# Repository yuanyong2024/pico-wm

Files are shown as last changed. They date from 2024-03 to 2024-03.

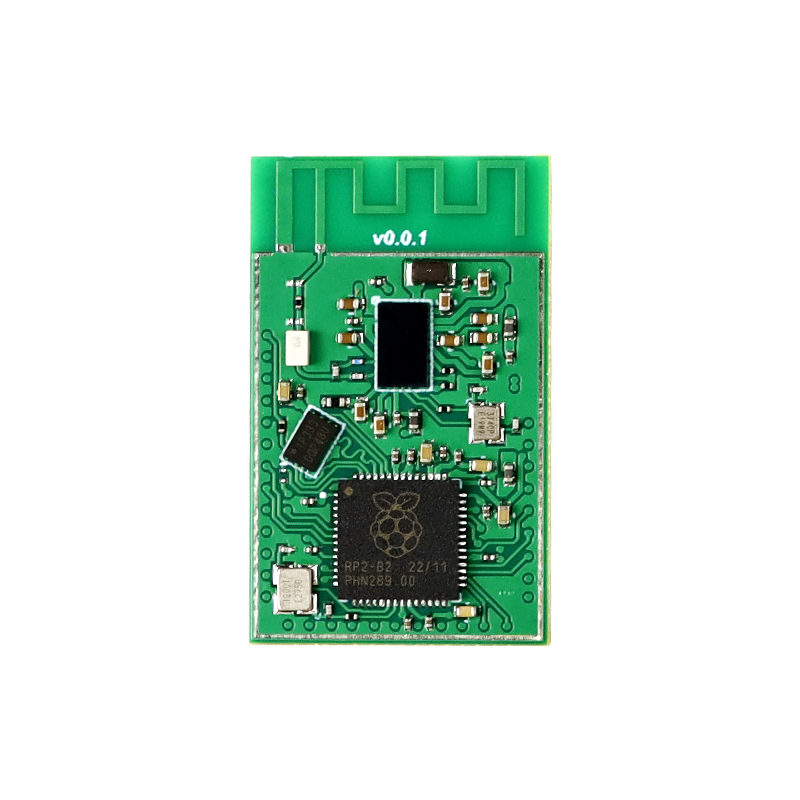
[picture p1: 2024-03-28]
pictures/2.jpg

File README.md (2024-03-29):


# Introduction
As a hardware engineer, it's always have difficulties to coding in python than C.Plus,I'm a fan of Raspberry Pi's hardware. So when they release the pico w and when i saw the schematic for it. 
I was thinking well I should build one module based on that architecture with below several reasons
1. Keep motivated on learn circuitpython.
2. Learn how to design a compact module.
3. improve the skill of tuning the antenna.
4. gain more on how to design a product.
5. I name it pico wm (pico w means its a variant of official Raspberry Pi pico w and m means it's a module)
So there is. I made it work even at the first verison. And optimized a little bit on v0.0.2. Probably there is a v0.0.3 if I find out something that need to get improved.

# Features:
1. use the same wifi chip(infineon CY43439) and circuitry like pico w. So wirelss function api is exactly the same(not like most of the rp2040+esp solution on market)
2. Flash size is the same like pico w (16Mb)
3. 6 layer board design with a complete ground on bottom layer. Improved the signal integraty. But also increased the costs -:(
4. compact size(28.5x17.5mm), so that it can be suitable for most of the situation.
5. All the GPIO had been exposed at the bottom side in a LGA footprint.
6. 50ohm impedance achieved for the RF trace.
7. onboard WiFi/BLE antenna.But obviously not as good as official pico w for now -:(
8. Reserved for a top shield cover feature.
9. all  the vias on the pcb is filled plating.
10. optimize the power topology, make it easier to design the carrier board based on this module.
11. Ofcourse totally open-sourced.

# Limitations:
1. The only limitation for this module would be the RF performance, Still need more time to tuning it.
2. And because I need to make sure the module is functioning well after SMT, so I didnot populate the shield cover yet.

# considering support me?
Building the module definitley take time and energy.
And also it's cost a lot. As the module itself is a six layer board and I'm using the expensive Infineon chip. So I would appreciate anyone who can support me by purchase it from [this link](https://www.elecrow.com/pico-wm.html)

# Attentions:
1. This is just a module. So need customer build a carrier board for it.
2. Those who interested in this module can use the picoduino as a start point and use the pico w m schematic and pcb lib from that picoduino open source file.
3. I will also build a feather compatible one later.

# useful links:
[pico w datasheet](https://datasheets.raspberrypi.com/picow/pico-w-datasheet.pdf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..)

[raspberry pi pico documentation](https://www.raspberrypi.com/documentation/microcontrollers/raspberry-pi-pico.html#raspberry-pi-pico-w)

[picoduino design file](https://github.com/yuanyong2024/picoduino)

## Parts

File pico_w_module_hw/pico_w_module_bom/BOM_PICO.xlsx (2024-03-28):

Designator | Quantity | Footprint | MFG | PN | Value
U4 | 1 | USON8_3X2MM | WINBOND | W25Q16JVUXIQ | N/A
U3 | 1 |  | Raspberrypi | RP2040 | N/A
U2 | 1 | LFB212G45CG7D227 | muRata | LFB212G45CG7D227 | N/A
U1 | 1 | CY43439 | Infineon | CYW43439KUBG | N/A
R8, R9 | 2 | R0201 | YAGEO | RC0201FR-071KL | 1K
R5 | 1 | R0201 | YAGEO | AF0201JR-07220RL | 220R
R4 | 1 | R0201 | YAGEO | RC0201FR-070RL | 0R
R3 | 1 | R0402 | YAGEO | RC0402FR-0722RL | 22R
R2 | 1 | R0201 | YAGEO | RC0201JR-0710KL | 10K
R1 | 1 | R0201 | YAGEO | RC0201DR-07470RL | 470R
Q2 | 1 | 2520 | EPSON | Q24FA20H00687 | 12MHz
Q1 | 1 | Q22FA12800078 | EPSON | Q22FA12800078 | 37.4MHz
L2 | 1 | l0201 | muRata | LQP03PN4N7J02D | 4.7nH
L1 | 1 | L0805 | TAIYO YUDEN | BRC2012T2R2MD | 2.2uH
FB1, FB2, FB3 | 3 | L0402 | muRata | BLM15AG601SN1D | 600R@100MHz
C23, C25, C26, C30, C40 | 5 | C0402 | muRata | GRM155R61A106ME44D | 10uF
C18, C19 | 2 | C0201 | muRata | GRM0335C1H150FA01D | 15pF
C16, C17 | 2 | C0201 | muRata | GRM0335C1H180JA01D | 18pF
C12, C15 | 2 | C0201 | muRata | GRM0335C1H100JA01D | 10pF
C8, C10, C20, C21, C24, C27, C28, C29, C31, C32, C33, C34, C35, C36, C37, C38, C39 | 17 | C0201 | muRata | GRM033Z71A104KE14D | 0.1uF
C1, C2, C3, C4, C5, C6, C7, C9, C11, C22 | 10 | C0402 | muRata | GRM155R61A475KEAAD | 4.7uF

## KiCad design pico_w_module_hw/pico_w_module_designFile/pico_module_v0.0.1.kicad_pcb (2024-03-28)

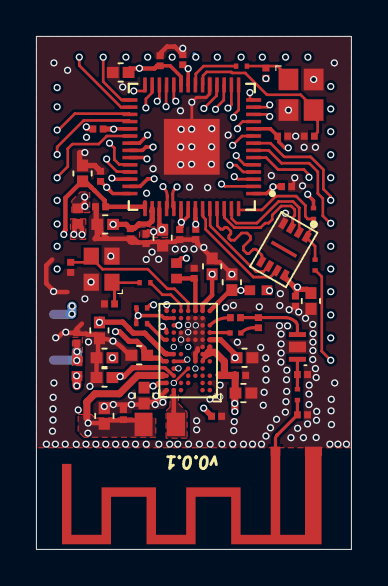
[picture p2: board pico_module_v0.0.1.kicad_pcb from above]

Board: 6 copper layers, 17.5 x 28.5 mm, 61 parts (0 on the bottom side), 70 nets.

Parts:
ANT1: U.FL-R-SMT-1(10); AN043_2.4GHZ
C1, C2, C3, C4, C5, C6, C7, C9, C11, C22, C23, C25, C26, C30, C40: C0402 12pF 50V; C0402
C8, C10, C20, C21, C31: C0402 12pF 50V; C0201
C12, C13, C14, C15, C16, C17, C18, C19, C24, C27, C28, C29, C32, C33, C34, C35, C36, C37, C38, C39: C0201 DNP; C0201
FB1, FB2, FB3: Ferrite 33Ohm 6A; L0402
L1: Inductor 6.8uH 30%; L0805
L2: L0603 470nH 1.4A; l0201
Q1: 37.4MHz; Q22FA12800078
Q2: 12MHz; 2520
R1, R2, R4, R5, R8, R9, R10: R0402 DO NOT PLACE; R0201
R3: R0402 1K 5% 1/16W; R0402
U1: CYW43439KUBG; CY43439
U2: LFB212G45CG7D227
U3: RP2040
U4: W25Q16JVUXIQ; USON8_3X2MM
U5: PICO_W_MODULE; PICO_M_SMT

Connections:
1.1V: C25.2, C26.2, C27.2, C28.2, C29.2, U3.23, U3.45, U3.50
ADC_REF: C23.2, C24.2, U3.43, U5.36
BOOTSEL: R9.2, U5.2
GND: ANT1.2, ANT1.3, C1.1, C2.1, C3.1, C4.1, C5.1, C6.1, C7.1, C8.1, C9.1, C10.1, C11.1, C13.1, C14.1, C16.1, C17.1, C18.1, C19.1, C20.1, C21.1, C22.1, C23.1, C24.1, C25.1, C26.1, C27.1, C28.1, C29.1, C30.1, C31.1, C32.1, C33.1, C34.1, C35.1, C36.1, C37.1, C38.1, C39.1, C40.1, Q1.2, Q1.4, Q2.2, Q2.4, U1.A7, U1.B1, U1.B6, U1.D4, U1.E3, U1.G2, U1.H2, U1.H3, U1.H4, U1.J2, U1.J3, U1.J5, U1.K2, U1.L2, U1.L3, U1.L4, U2.G, U3.19, U3.57, U4.4, U5.1, U5.15, U5.27, U5.37, U5.39, U5.41
GPIO0: U3.2, U5.3
GPIO1: U3.3, U5.4
GPIO2: U3.4, U5.5
GPIO3: U3.5, U5.6
GPIO4: U3.6, U5.7
GPIO5: U3.7, U5.8
GPIO6: U3.8, U5.9
GPIO7: U3.9, U5.10
GPIO8: U3.11, U5.11
GPIO9: U3.12, U5.12
GPIO10: U3.13, U5.13
GPIO11: U3.14, U5.14
GPIO12: U3.15, U5.16
GPIO13: U3.16, U5.17
GPIO14: U3.17, U5.18
GPIO15: U3.18, U5.19
GPIO16: U3.27, U5.23
GPIO17: U3.28, U5.24
GPIO18: U3.29, U5.25
GPIO19: U3.30, U5.26
GPIO20: U3.31, U5.30
GPIO21: U3.32, U5.31
GPIO22: U3.34, U5.32
GPIO26: U3.38, U5.33
GPIO27: U3.39, U5.34
GPIO28: U3.40, U5.35
MCU_VDD: FB3.1, U5.38
M_USB_N: U3.46, U5.29
M_USB_P: U3.47, U5.28
M_VCC: C30.2, C32.2, C33.2, C34.2, C35.2, C36.2, C37.2, C38.2, C39.2, C40.2, FB3.2, R10.2, U3.1, U3.10, U3.22, U3.33, U3.42, U3.44, U3.48, U3.49, U4.8
NetANT1_1: ANT1.1, C13.2, R4.1
NetC7_2: C7.2, R3.2, U1.H1
NetC8_2: C8.2, FB2.2, U1.M3
NetC12_1: C12.1, C15.2, U2.O
NetC12_2: C12.2, U1.K1
NetC14_2: C14.2, R4.2, U2.I
NetC15_1: C15.1, L2.1
NetC16_2: C16.2, Q1.3, U1.M4
NetC17_2: C17.2, Q1.1, R5.1
NetC18_2: C18.2, Q2.3, U3.20
NetC19_2: C19.2, Q2.1, R8.1
NetL1_1: L1.1, U1.A6
NetL2_2: L2.2, U1.J1
NetR1_2: R1.2, U1.K6
NetR2_2: R2.2, U1.H7
NetR5_2: R5.2, U1.M5
NetR8_2: R8.2, U3.21
NetU1_E6: U1.E6, U1.G6, U3.35
QSPI_SCLK: U3.52, U4.6
QSPI_SD0: U3.53, U4.5
QSPI_SD1: U3.55, U4.2
QSPI_SD2: U3.54, U4.3
QSPI_SD3: U3.51, U4.7
RF_VDD: C31.2, FB1.1, U5.40
RUN: U3.26, U5.22
SDIO_CLK: U1.M7, U3.41
SDIO_CS: U1.J7, U3.37
SDIO_DIO: R1.1, R2.1, U1.L6, U1.L7, U3.36
SWCLK: U3.24, U5.20
SWDIO: U3.25, U5.21
VDD_BAT: C11.2, C22.2, FB1.2, U1.B7, U1.F6, U1.F7
VIN_LDO: C1.2, C2.2, C20.2, L1.2, U1.C7, U1.M2
VOUT_3P3: C5.2, C6.2, R3.1, U1.E7, U1.M1
VOUT_CORE: C3.2, C10.2, U1.C6, U1.D3, U1.G4
VOUT_LN: C4.2, C9.2, C21.2, FB2.1, U1.D6, U1.E2, U1.F1, U1.F2, U1.G1
~QSPI_SS: R9.1, R10.1, U3.56, U4.1

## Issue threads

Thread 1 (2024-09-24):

Questions about PICO-WM

metermult, 2024-09-24:
Hello,

I have several questions and want to pick your brain as to how the development of this product was completed and if v0.0.2 or v0.0.3 is on the horizon.
1) What simulation software did you use for the antenna? I believe that there was a few vias as well that may be just a little far apart but I was just visually looking.
2) Do you plan on supporting the [rp2350](https://www.raspberrypi.com/products/raspberry-pi-pico-2/) in the near future?

I will buy and will take a look at this. Maybe do some signal analysis on the device and let you know what.

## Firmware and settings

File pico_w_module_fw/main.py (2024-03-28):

from machine import UART,Pin,I2C
import network
import socket
import time

led = Pin(16,Pin.OUT)
led.value(1)

timeout_count = 2
while timeout_count:
    print(f"timeout count {timeout_count} before setting up the Wi-Fi config")
    timeout_count-=1
    time.sleep(1)
    
print("\r\nWelcome to the setup process for picoduino, Please follow below three steps to control the onboard led via browser\r\n")
print('Please input your Wi-Fi name:')
wifi_name = input()
print(f'your Wi-Fi name is "{wifi_name}",now please input your Wi-Fi password')
password = input()
print(f'your Wi-Fi password is "{password}"')
print("well done, your picoduino now is trying to connect to your Wi-Fi network")




#connect to wifi router and return the ip
def connect():
    #Connect to WLAN
    wlan = network.WLAN(network.STA_IF)
    wlan.active(True)
    wlan.connect(wifi_name, password)
    retry_count = 10
    while wlan.isconnected() == False:
        print('Waiting for connection...')
        #blink for 1s insted of delay 1s
        for i in range(5):
            led.value(0)
            time.sleep(0.1)
            led.value(1)
            time.sleep(0.1)
            
        retry_count-=1
        if retry_count==0:
            break
    
    if retry_count == 0:
        print("ooops, picoduino cannot connect to you Wi-Fi network, please check your Wi-Fi name and password and press reset button for a pretry.!!!!!!!!!!")
        while True:
            led.value(0)
            time.sleep(1)
            led.value(1)
            time.sleep(1)
        
    led.value(1)   
    ip = wlan.ifconfig()[0]
    print(f'Connected on {ip}')
    print("\r\nPlease copy the above ip address to browser and press enter(or return on MAC OS)")
    print("And have fun with thet LED on and off example -:)")
    return ip

  
def open_socket(ip):
    # Open a socket
    address = (ip, 80)
    connection = socket.socket()
    connection.bind(address)
    connection.listen(1)
    return connection


  
#only turn on and off led in webpaage.  
def webpage(state):
    #Template HTML
    html = f"""
            <!DOCTYPE html>
            <html>
            <form action="./lighton">
            <input type="submit" value="Light on" />
            </form>
            <form action="./lightoff">
            <input type="submit" value="Light off" />
            </form>
            <p>LED is {state}</p>
            </body>
            </html>
            """
    return str(html)
    
    
#start a web server    
def serve(connection):
    #Start a web server
    state = 'OFF'
    temperature = 0
    while True:
        client = connection.accept()[0]
        request = client.recv(1024)
        request = str(request)
        try:
            request = request.split()[1]
        except IndexError:
            pass
        if request == '/lighton?':
            led.value(1)
            state = 'ON'
            print("LED is on now")
        elif request =='/lightoff?':
            led.value(0)
            state = 'OFF'
            print("LED is off now")
        client.send(webpage(state))
        client.close()
        
        
        
try:
    ip = connect()
    connection = open_socket(ip)
    serve(connection)
except KeyboardInterrupt:
    machine.reset()
        
